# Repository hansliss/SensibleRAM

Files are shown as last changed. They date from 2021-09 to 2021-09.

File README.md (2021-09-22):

# SensibleRAM

## NOTE: This doesn't currently work in a real VIC-20, since the address decoding for the VIA chips is incomplete, so they collide with this memory! I'm testing another patch to take care of that problem.

_A RAM expansion to make your VIC-20 more sensible_

This is actually how the VIC-20 should have been designed in the first place, hence the name SensibleRAM. It would have saved us all some headaches back in the day.

You may already know that there are many different cool modern memory expansion cartridges for the VIC-20 nowadays, providing up to 35-37kB of expansion memory. Some of that memory can benefit from this hack _if you are using BASIC_, whilst some of it is not relevant here. The aim here is to provide BASIC with as much memory as possible, regardless of what memory expansions you have.

_Before you spend a lot of time on this, please be aware that this is anachronistic nerdery of the highest degree. What this does would have been really cool in 1981. Forty years later, in 2021, not so much._

_Note that this hardware is as yet untested. The software has been tested in a patched VICE, however. Once I receive the boards and can test it properly, I'll update this and add some photos._

## Background

The VIC-20 has a somewhat confusing memory map. It comes with 5kB of system RAM as standard, with 1k at the bottom of the memory map, and 4k at $1000. To BASIC, those upper 4k are available as working memory, minus 0.5k that is used by the system for screen memory.

Normally, the screen memory is located at $1E00, so BASIC memory is $1000-$1DFF which is 3584 bytes. One byte is always consumed by BASIC, so the computer reports 3583 bytes free.

If you add a 3k RAM expansion, it will be located at $0400-0FFF, and the available space increases to 6655 bytes.

If you add larger expansions, they will start att BLK1 at $2000 and expand upwards until they reach $7FFF. However, when this happens, the screen memory becomes a problem, since at $1E00, it will split the system RAM in two non-contiguous parts. That won't do, so the screen memory is moved to $1000 if you add memory to BLK1, and all the memory between $1200 and $7FFF becomes usable to BASIC.

However, with one of those larger expansions in place, any 3k memory at $0400 becomes unusable to BASIC, since it ends up outside the contiguous area.

All this has two negative effects on the system:
1. The screen memory placement at either $1E00 or $1000 precludes any chance of getting contiguous memory between $0400 and $7FFF
1. the screen memory eats up 512 bytes that could have been used as BASIC memory.

## The hardware

The reason that the screen memory is located in one of those places as opposed to $0400 or $7E00 is the way the VIC chip is wired into the system. The screen memory has to be shared between the CPU and the VIC, and the VIC can only address 16k of memory.

The way this has been handled is that the VIC chip shares two different blocks with the CPU, BLK0 and BLK4. The VIC chip has 14 address bits. VA0-VA12 are connected via a tri-state buffer (controlled by a clock pin, but let's leave bus sharing out of this) to the CPU's CA0-CA12, but the most significant bit VA13 is connected to the active-low block selector /BLK4. This means that what the CPU sees as $0000-$1FFF, the VIC sees as $2000-$3FFF, and what the CPU sees as $8000-$9FFF is $0000-1FFF to the VIC.

There's also a mechanism explicitly blocking the VIC chip from sharing some areas with the CPU. Those include the three RAM blocks RAM[1-3] at $0400, the main expansion and ROM blocks BLK[1,2,3,5,6,7] (which have to be blocked since the VIC chip can't address them), and the two auxiliary I/O areas I/O2 and I/O3, located within BLK4. On top of that, the expansions we talked about earlier are all cartridge expansions, so they are sitting on the CPU bus rather than the VIC bus, which means they are unavailable to the VIC anyway.

## Conclusion

So, we're left with choosing an area within the interval $1000-$1FFF for the screen memory, since the first kB in BLK0 is used by the OS (although you can map the screen memory to the zero page, for a fun exercise), and BLK4, which is used only for the character ROM, the colour RAM and the I/O registers, doesn't have any available RAM.

Tough.

## The fix

_However_, the I/O registers at I/O0 ($9000-$93FF) take up far less than the entire interval, with the highest register at $912F. This leaves $9200-$93FF entirely free, and this area is addressable to both the CPU and the VIC.

So, this project adds 512 bytes of RAM to $9200, and with the included programs you can move the screen memory to this area on your VIC, freeing up 512 bytes of BASIC RAM. If you have both 3k and 8k+ expansions, you can also add those 3k to your available BASIC RAM, for a whopping total win of 3500 bytes.

The included assembly program will try to move the screen memory and start/end memory pointers as correctly as possible regardless of what memory expansions are present, and will then reinitialize BASIC.

Here's a short BASIC program that does the same, but assumes you have expansions in RAM[1-3] and BLK[1-3]:
```
10pO36866,pE(36866)or128:pO36869,(pE(36869)and15)or(4*16)
20pO648,146:pO44,4:pO43,1:pO56,128:pO55,0:pO642,4
30pO641,0:pO644,128:pO643,0:pO1024,0:sys58232
```

## The effects

Here are some examples of what happens when you use this with different expansions:

|Expansion|Orig. free ram|Orig max array size|New free RAM|New max array size|RAM increase|
|---|---|---|---|---|---|
|None |3583 |1119 |4095 |1289 |512 |
|RAM[1-3] |6655 |2143 |7167 |2313 |512 |
|BLK1 |11775 |3848 |12287 |4021 |512
|RAM[1-3],<br>BLK1 |11775 |3848 | 15359 |5043 |3584 |
|BLK[1-2] |19967 |6581 |20479 |6751 |512 |
|RAM[1-3],<br>BLK[1-2] |19967 |6581 |23551 |7774 |3584 |
|BLK[1-3] |28159 |9310 |28671 |9480 |512 |
|RAM[1-3],<br>BLK[1-3] |28159 |9310 |31743 |10505 |3584 |

The "max array size" fields come from an experiment I did, using the BASIC program __testmem.bas__ that DIM'd string arrays of increasing size and filled them with strings, until no more memory was left. This program would have taken a week to run at the largest memory sizes, had I not run it in warp mode in VICE (see VICE_patching_notes.md).

## The future
Feel free to build on this! One possible addition would be to add an I/O location at, say $91FF, that causes the character ROM to be detached from the CPU bus and replaced with RAM, for an additional 4k of available RAM at $8000 - $8FFF, which is within the contiguous section. This would increase free space to 35839 bytes. Since this design uses a 32k chip which is 99.4% wasted, this would be a noble use of some of 
the space.

Please let me know what you come up with, and let me know if you actually try this thing out.

## Some technical notes without any explanatory text
```
bit 7 of $9002 controls A9 of screen memory and A9 of color memory
bit 4-7 of $9005 controls A10-A13 of VIC screen memory. A13 is /BLK4 to the CPU

$9200 = 1001 0010 0000 0000 = (VIC) b01001 000000000
$93FF = 1001 0011 1111 1111 = (VIC) b01001 111111111

!(A9 & A12 & !(A10 | A11 | A13))

A9:
$9002.7 = 1

A10-13:
$9005.4-7 = 0100
```

§1

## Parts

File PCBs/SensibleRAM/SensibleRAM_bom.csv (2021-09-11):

Comment | Designator | Footprint | LCSC
MOS6561_socket | U1 | Housings_DIP:DIP-40_W15.24mm
MOS6561 | U2 | Housings_DIP:DIP-40_W15.24mm
SN74LVC1G27DBVR | U3 | TO_SOT_Packages_SMD:SOT-23-6_Handsoldering | C128410
SN74LVC1G10DBVR | U4 | TO_SOT_Packages_SMD:SOT-23-6_Handsoldering | C403721
CY62256-70PC | U5 | VIC-20:SOP-28W_330mil_Pitch1.27mm | C261868

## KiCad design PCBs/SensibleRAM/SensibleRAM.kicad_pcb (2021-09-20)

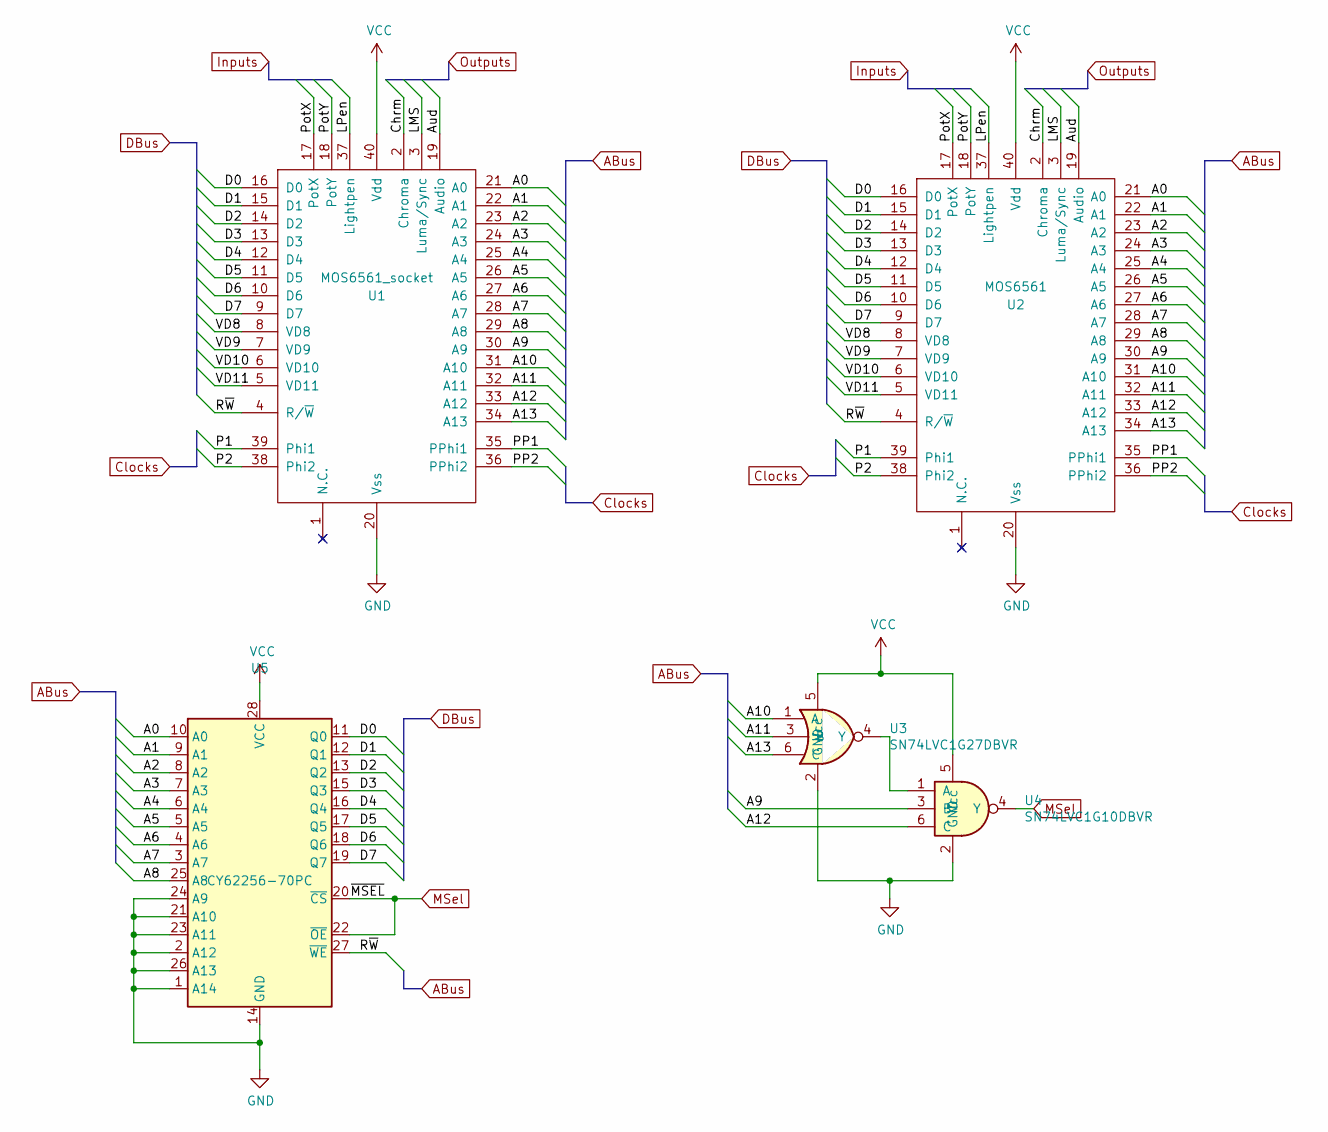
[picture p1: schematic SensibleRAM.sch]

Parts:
U1: MOS6561_socket; DIP-40_W15.24mm
U2: MOS6561; DIP-40_W15.24mm
U3: SN74LVC1G27DBVR; SOT-23-6_Handsoldering; LCSC C128410
U4: SN74LVC1G10DBVR; SOT-23-6_Handsoldering; LCSC C403721
U5: CY62256-70PC; SOP-28W_330mil_Pitch1.27mm; LCSC C261868

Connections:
/A0: U1.21 (A0), U2.21 (A0), U5.10 (A0)
/A1: U1.22 (A1), U2.22 (A1), U5.9 (A1)
/A2: U1.23 (A2), U2.23 (A2), U5.8 (A2)
/A3: U1.24 (A3), U2.24 (A3), U5.7 (A3)
/A4: U1.25 (A4), U2.25 (A4), U5.6 (A4)
/A5: U1.26 (A5), U2.26 (A5), U5.5 (A5)
/A6: U1.27 (A6), U2.27 (A6), U5.4 (A6)
/A7: U1.28 (A7), U2.28 (A7), U5.3 (A7)
/A8: U1.29 (A8), U2.29 (A8), U5.25 (A8)
/A9: U1.30 (A9), U2.30 (A9), U4.3 (B)
/A10: U1.31 (A10), U2.31 (A10), U3.1 (A)
/A11: U1.32 (A11), U2.32 (A11), U3.3 (B)
/A12: U1.33 (A12), U2.33 (A12), U4.6 (C)
/A13: U1.34 (A13), U2.34 (A13), U3.6 (C)
/Aud: U1.19 (Audio), U2.19 (Audio)
/Chrm: U1.2 (Chroma), U2.2 (Chroma)
/D0: U1.16 (D0), U2.16 (D0), U5.11 (Q0)
/D1: U1.15 (D1), U2.15 (D1), U5.12 (Q1)
/D2: U1.14 (D2), U2.14 (D2), U5.13 (Q2)
/D3: U1.13 (D3), U2.13 (D3), U5.15 (Q3)
/D4: U1.12 (D4), U2.12 (D4), U5.16 (Q4)
/D5: U1.11 (D5), U2.11 (D5), U5.17 (Q5)
/D6: U1.10 (D6), U2.10 (D6), U5.18 (Q6)
/D7: U1.9 (D7), U2.9 (D7), U5.19 (Q7)
/LMS: U1.3 (Luma/Sync), U2.3 (Luma/Sync)
/LPen: U1.37 (Lightpen), U2.37 (Lightpen)
/P1: U1.39 (Phi1), U2.39 (Phi1)
/P2: U1.38 (Phi2), U2.38 (Phi2)
/PP1: U1.35 (PPhi1), U2.35 (PPhi1)
/PP2: U1.36 (PPhi2), U2.36 (PPhi2)
/PotX: U1.17 (PotX), U2.17 (PotX)
/PotY: U1.18 (PotY), U2.18 (PotY)
/R~W: U1.4 (R/~W), U2.4 (R/~W), U5.27 (~WE)
/VD8: U1.8 (VD8), U2.8 (VD8)
/VD9: U1.7 (VD9), U2.7 (VD9)
/VD10: U1.6 (VD10), U2.6 (VD10)
/VD11: U1.5 (VD11), U2.5 (VD11)
GND: U1.20 (Vss), U2.20 (Vss), U3.2 (GND), U4.2 (GND), U5.1 (A14), U5.2 (A12), U5.14 (GND), U5.21 (A10), U5.23 (A11), U5.24 (A9), U5.26 (A13)
MSel: U4.4 (Y), U5.20 (~CS), U5.22 (~OE)
unnamed: U3.4 (Y), U4.1 (A)
VCC: U1.40 (Vdd), U2.40 (Vdd), U3.5 (Vcc), U4.5 (Vcc), U5.28 (VCC)

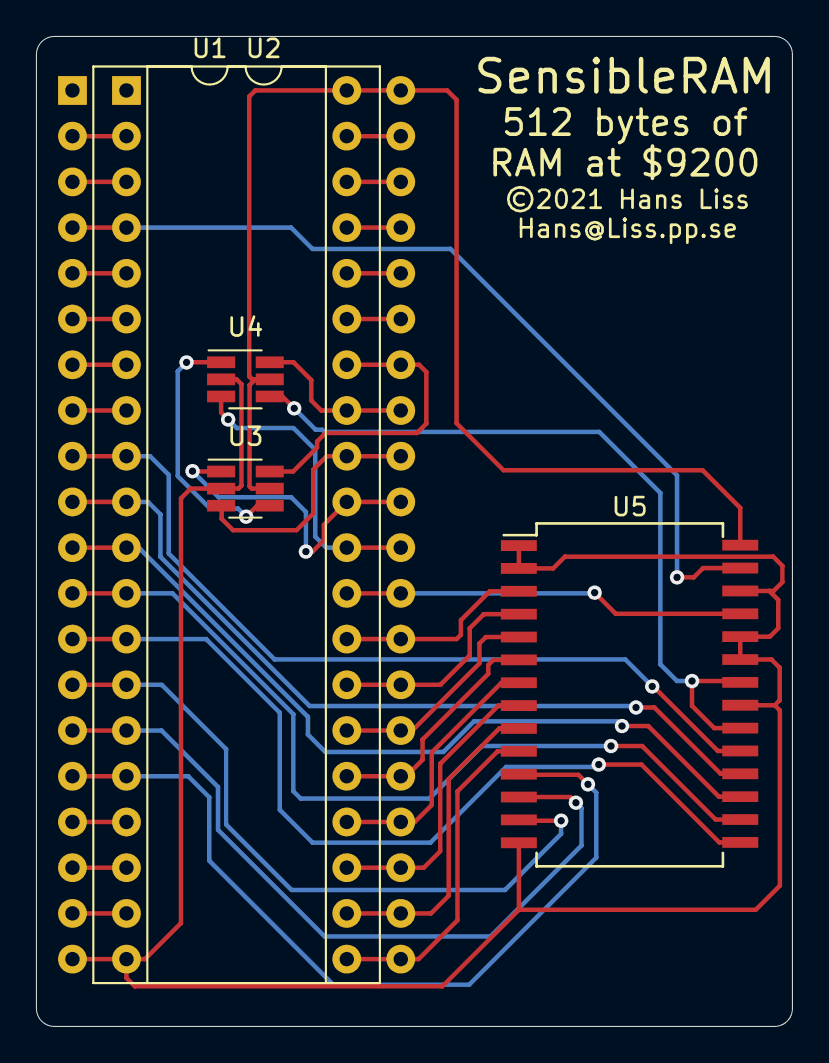
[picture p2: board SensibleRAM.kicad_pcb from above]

Board: 2 copper layers, 42.0 x 55.0 mm, 5 parts (0 on the bottom side), 41 nets.

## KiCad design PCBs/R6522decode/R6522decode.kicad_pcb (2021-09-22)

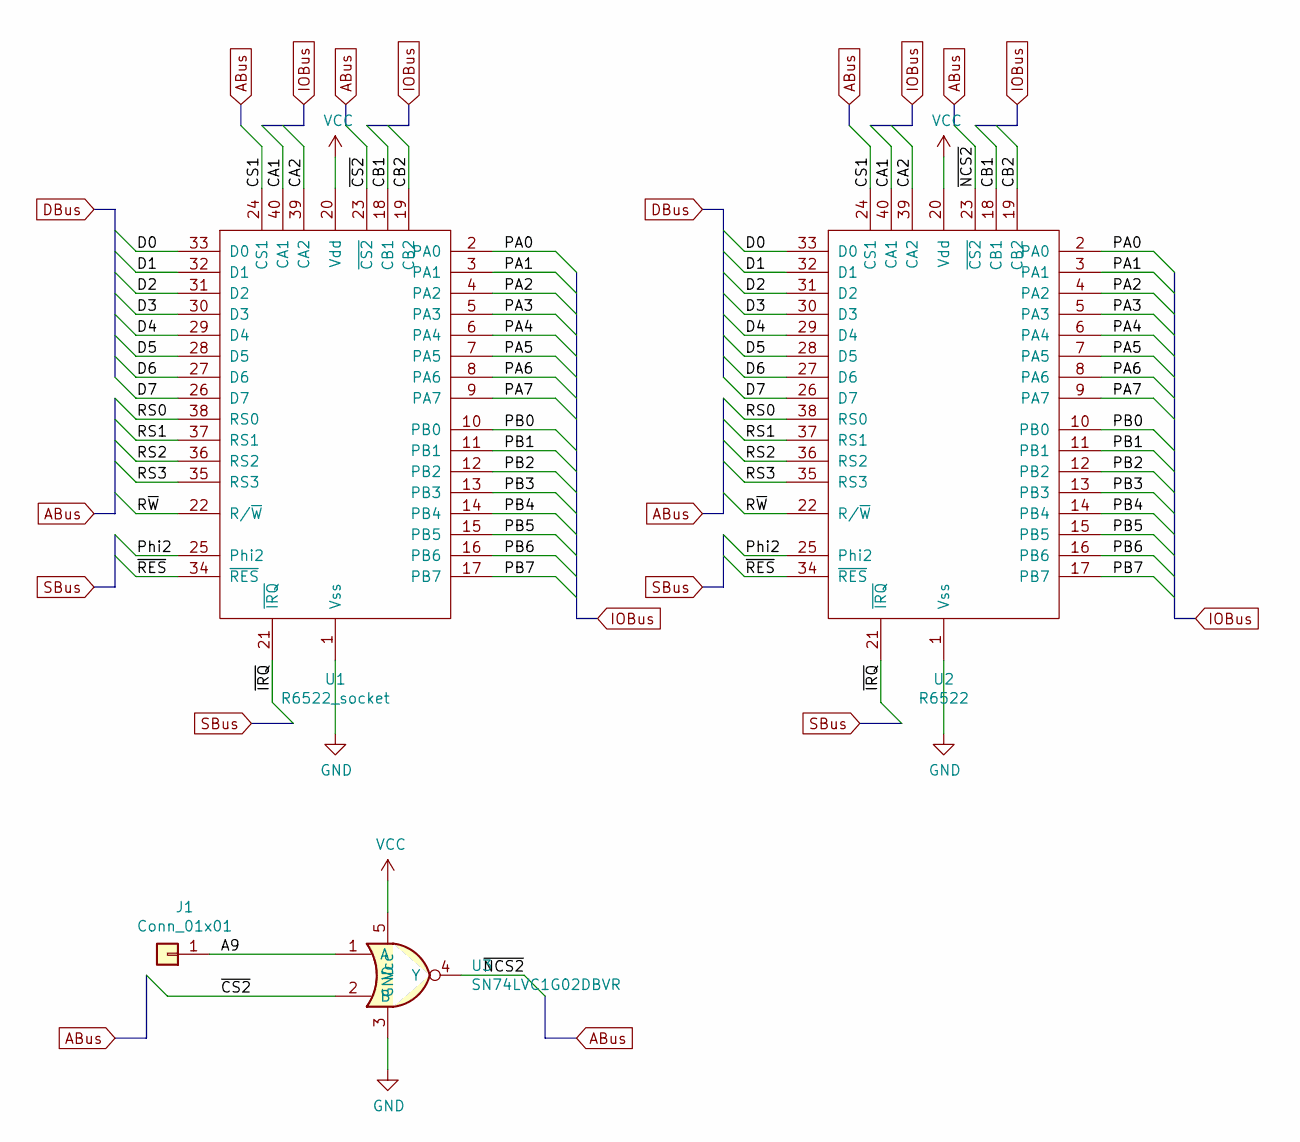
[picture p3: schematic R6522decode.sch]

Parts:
J1: Conn_01x01; Pin_Header_Straight_1x01_Pitch2.54mm
U1: R6522_socket; DIP-40_W15.24mm
U2: R6522; DIP-40_W15.24mm
U3: SN74LVC1G02DBVR; SOT-23-6_Handsoldering; LCSC C16360

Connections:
/A9: J1.1, U3.1 (A)
/CA1: U1.40 (CA1), U2.40 (CA1)
/CA2: U1.39 (CA2), U2.39 (CA2)
/CB1: U1.18 (CB1), U2.18 (CB1)
/CB2: U1.19 (CB2), U2.19 (CB2)
/CS1: U1.24 (CS1), U2.24 (CS1)
/D0: U1.33 (D0), U2.33 (D0)
/D1: U1.32 (D1), U2.32 (D1)
/D2: U1.31 (D2), U2.31 (D2)
/D3: U1.30 (D3), U2.30 (D3)
/D4: U1.29 (D4), U2.29 (D4)
/D5: U1.28 (D5), U2.28 (D5)
/D6: U1.27 (D6), U2.27 (D6)
/D7: U1.26 (D7), U2.26 (D7)
/PA0: U1.2 (PA0), U2.2 (PA0)
/PA1: U1.3 (PA1), U2.3 (PA1)
/PA2: U1.4 (PA2), U2.4 (PA2)
/PA3: U1.5 (PA3), U2.5 (PA3)
/PA4: U1.6 (PA4), U2.6 (PA4)
/PA5: U1.7 (PA5), U2.7 (PA5)
/PA6: U1.8 (PA6), U2.8 (PA6)
/PA7: U1.9 (PA7), U2.9 (PA7)
/PB0: U1.10 (PB0), U2.10 (PB0)
/PB1: U1.11 (PB1), U2.11 (PB1)
/PB2: U1.12 (PB2), U2.12 (PB2)
/PB3: U1.13 (PB3), U2.13 (PB3)
/PB4: U1.14 (PB4), U2.14 (PB4)
/PB5: U1.15 (PB5), U2.15 (PB5)
/PB6: U1.16 (PB6), U2.16 (PB6)
/PB7: U1.17 (PB7), U2.17 (PB7)
/Phi2: U1.25 (Phi2), U2.25 (Phi2)
/RS0: U1.38 (RS0), U2.38 (RS0)
/RS1: U1.37 (RS1), U2.37 (RS1)
/RS2: U1.36 (RS2), U2.36 (RS2)
/RS3: U1.35 (RS3), U2.35 (RS3)
/R~W: U1.22 (R/~W), U2.22 (R/~W)
/~CS2: U1.23 (~CS2), U3.2 (B)
/~IRQ: U1.21 (~IRQ), U2.21 (~IRQ)
/~NCS2: U2.23 (~CS2), U3.4 (Y)
/~RES: U1.34 (~RES), U2.34 (~RES)
GND: U1.1 (Vss), U2.1 (Vss), U3.3 (GND)
VCC: U1.20 (Vdd), U2.20 (Vdd), U3.5 (Vcc)

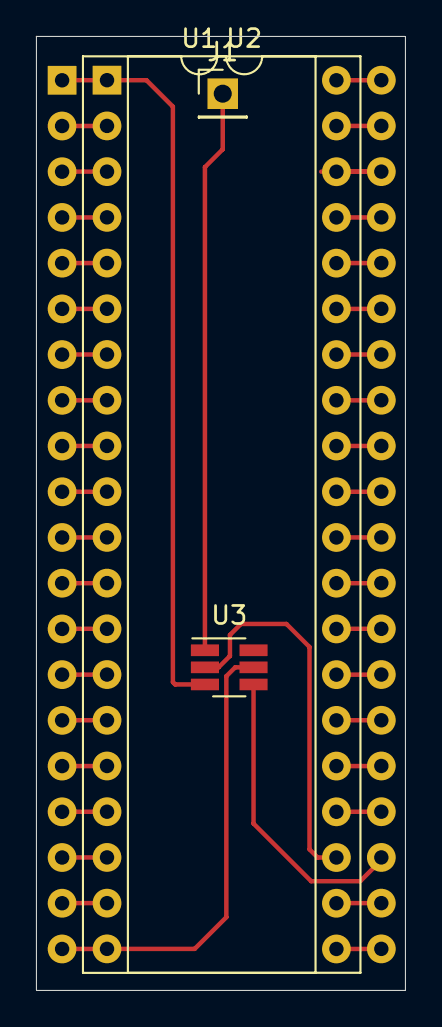
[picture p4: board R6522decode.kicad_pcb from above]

Board: 2 copper layers, 20.5 x 53.0 mm, 4 parts (0 on the bottom side), 42 nets.

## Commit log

2021-09-11 Initial import
    [SensibleRAM-B_Cu.gbr, SensibleRAM-B_Mask.gbr, SensibleRAM-B_Paste.gbr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]
2021-09-20 Moved init code to $1200 Fixed missing connection on PCB Added note about incomplete decoding to README
    [SensibleRAM-B_Cu.gbr, SensibleRAM-B_Mask.gbr, SensibleRAM-B_Paste.gbr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]
2021-09-20 Missed connection on PCB
    [SensibleRAM.kicad_pcb]
2021-09-22 Moved PCB designs down one level and added a new project for better address decoding for the VIAs.
    [R6522decode-B_Cu.gbr, R6522decode-B_Mask.gbr, R6522decode-B_Paste.gbr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]

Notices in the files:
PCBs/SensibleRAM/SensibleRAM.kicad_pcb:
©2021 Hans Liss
